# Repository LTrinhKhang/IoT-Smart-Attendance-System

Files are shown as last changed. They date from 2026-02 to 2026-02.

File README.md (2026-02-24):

# IoT Biometric Attendance System

Full-stack IoT biometric attendance system integrating custom PCB hardware, ESP32-S3 firmware, and a centralized Node.js backend.

This project demonstrates system-level engineering across hardware design, embedded development, and backend architecture.

---

## System Overview

The system consists of three major components:

1. **Hardware – ESP32-S3-Biometric-PCB**
   - Custom 2-layer PCB
   - TPS62130 synchronous buck regulator
   - ESP32-S3-WROOM module
   - TFT SPI display
   - Optical fingerprint sensor
   - Li-ion powered architecture

2. **Firmware – ESP32-S3-Firmware-Biometric**
   - Written in C++ (Arduino framework)
   - LVGL-based touchscreen UI
   - Fingerprint template handling (Base64 encoding/decoding)
   - Camera streaming support
   - HTTP client + WebSocket communication
   - NTP time synchronization

3. **Backend – Biometric-Attendance-Server**
   - Node.js + Express REST API
   - MySQL database
   - Real-time attendance logging
   - Face recognition (128D embedding)
   - Web dashboard for management and reporting

---

## High-Level Architecture

Edge Device (ESP32-S3)
→ HTTP REST / WebSocket
→ Node.js Server
→ MySQL Database

Biometric workflow:
- Face recognition using vector comparison
- Fingerprint verification via template matching
- Attendance event logging with timestamp

---

## Engineering Scope

This project covers:

- Custom PCB design with power integrity considerations
- High-frequency buck layout optimization (2.4 MHz switching)
- EMI mitigation strategies
- Embedded firmware architecture and state machine control
- Biometric data processing and encoding
- Backend API and database schema design
- Distributed IoT communication model

---

## Project Structure
- ESP32-S3-Biometric-PCB/ # Hardware design (KiCad + Gerber)
- ESP32-S3-Firmware-Biometric/ # ESP32 firmware
- Biometric-Attendance-Server/ # Node.js backend
- images/ # PCB renders and system illustrations

---

## Key Technical Highlights

- 3.3V rail designed for 1.5A peak load
- Oversized power trace for reduced IR drop
- Minimized buck hot-loop area
- Thermal vias under regulator
- Antenna keepout respected
- DRC-clean and fabrication-ready Gerber

---

## Setup Overview

### Hardware
Refer to:
`ESP32-S3-Biometric-PCB/README.md`

### Firmware
- Configure WiFi credentials
- Set server IP and port
- Flash using Arduino IDE or PlatformIO

### Server
- Install Node.js (v16+)
- Configure `.env`
- Run:  npm install
        node server/index.js

---

## Future Improvements

- Migration to 4-layer PCB for improved EMI control
- Enhanced transient response validation
- TLS-secured communication
- OTA firmware updates

---

## License

MIT (or specify applicable license)

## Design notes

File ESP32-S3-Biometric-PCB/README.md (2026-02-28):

# ESP32-S3 Biometric Attendance – Custom PCB Design

## Project Overview

This project presents a custom 2-layer PCB designed for a biometric attendance device based on ESP32-S3.  
The design integrates power management, high-speed SPI routing, and mixed-signal layout considerations in a compact form factor.

---
# Schematic Overview

<p align="center">
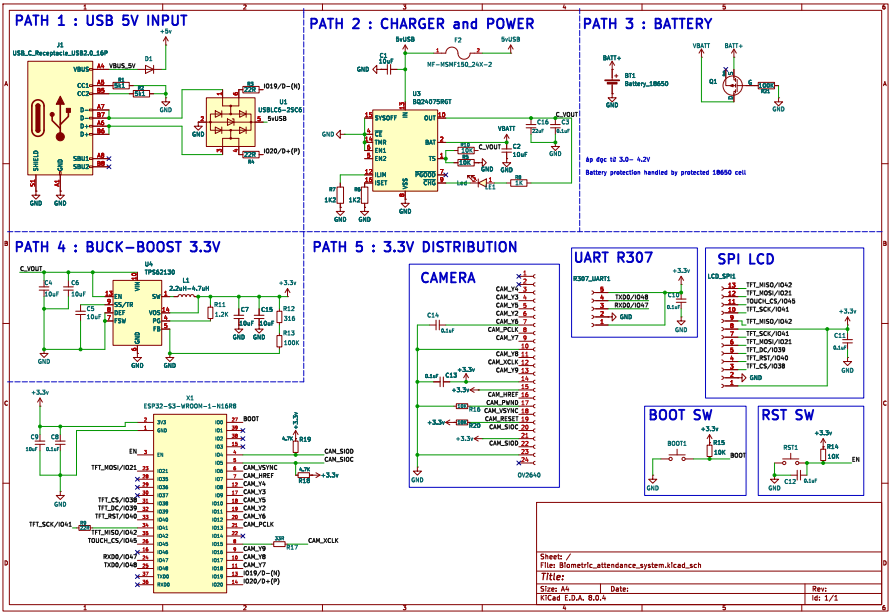
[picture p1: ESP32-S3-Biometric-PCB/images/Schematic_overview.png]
  
</p>

---

## PCB Layout Overview

### Top Copper Layer
<p align="center">
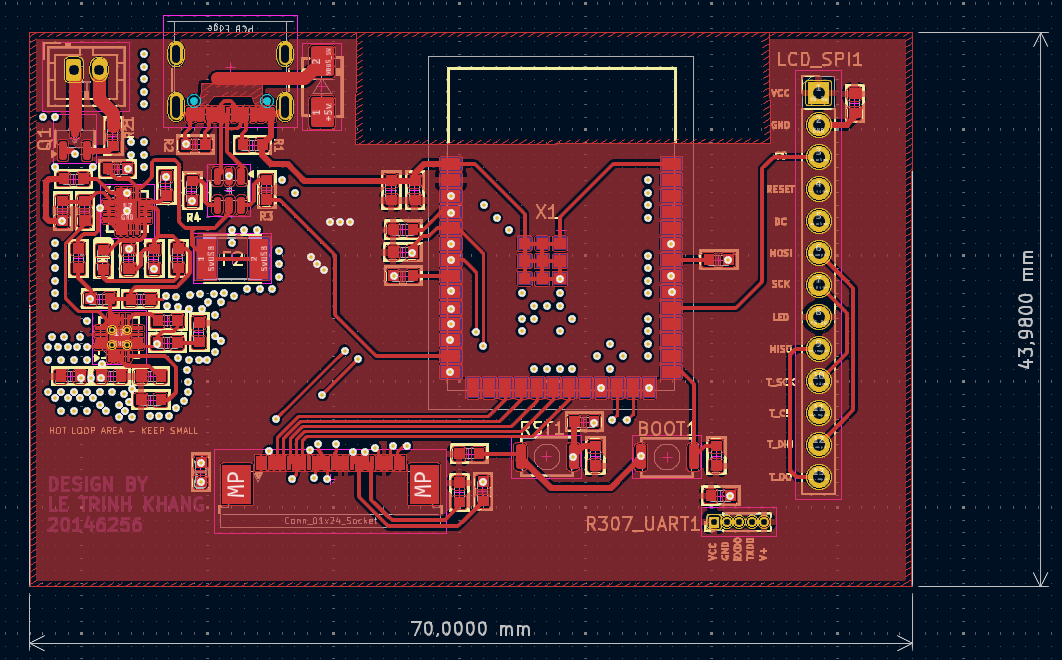
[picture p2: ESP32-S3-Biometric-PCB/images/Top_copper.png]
  
</p>

### Bottom Copper Layer
<p align="center">
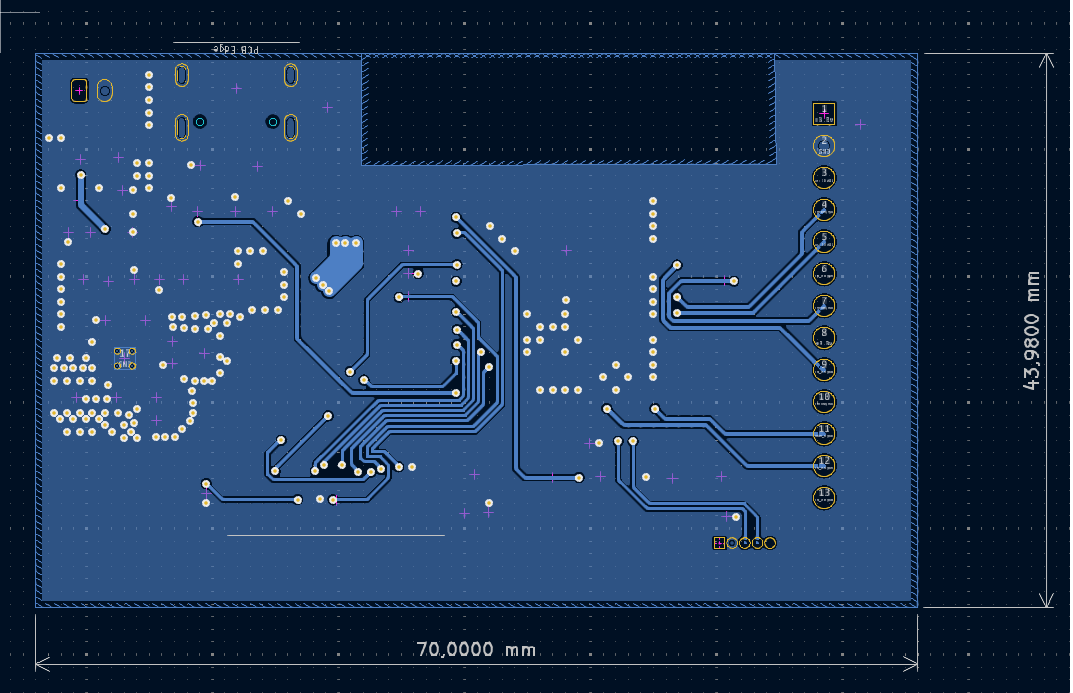
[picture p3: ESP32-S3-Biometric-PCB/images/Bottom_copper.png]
  
</p>

---

## Power Stage Layout (Buck Converter Optimization)

### Buck Layout – Hot Loop Minimization
<p align="center">
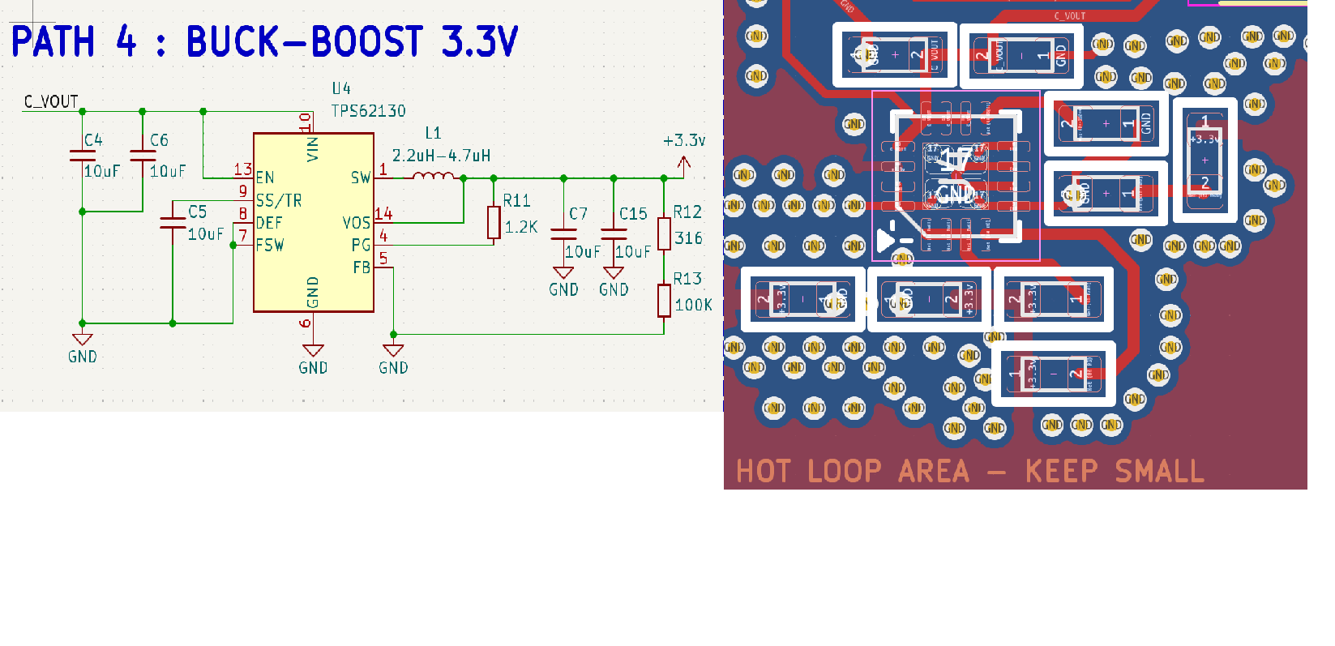
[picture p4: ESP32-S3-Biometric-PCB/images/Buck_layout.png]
  
</p>

The TPS62130 switching regulator layout prioritizes:

- Minimal VIN → SW → Inductor → CIN return loop area  
- Short SW node (~3 mm) to reduce radiated EMI  
- Tight PGND current return  
- Input capacitor placed within millimeters of VIN and PGND pins  

---

## 3D Board Rendering

### 3D Top View
<p align="center">
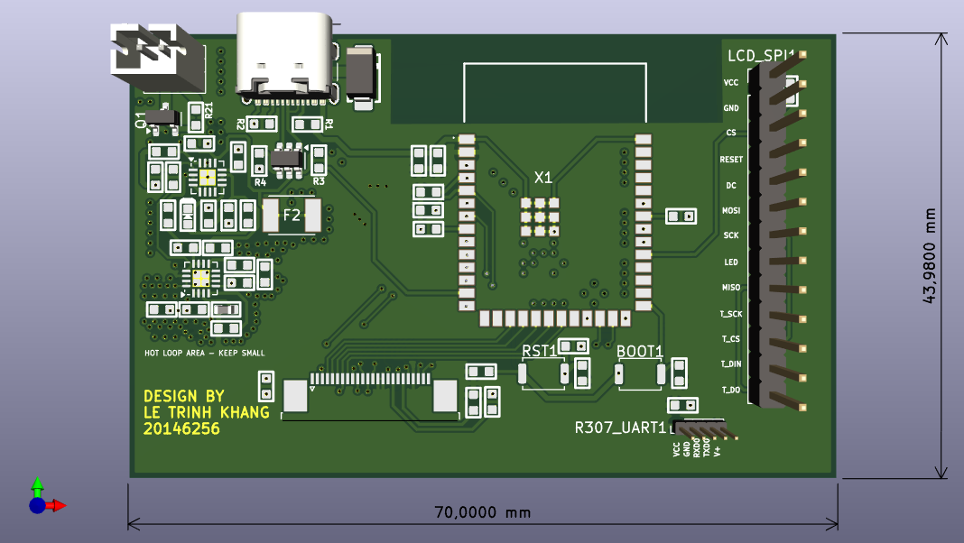
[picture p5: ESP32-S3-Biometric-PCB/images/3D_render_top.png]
  
</p>

### 3D Bottom View
<p align="center">
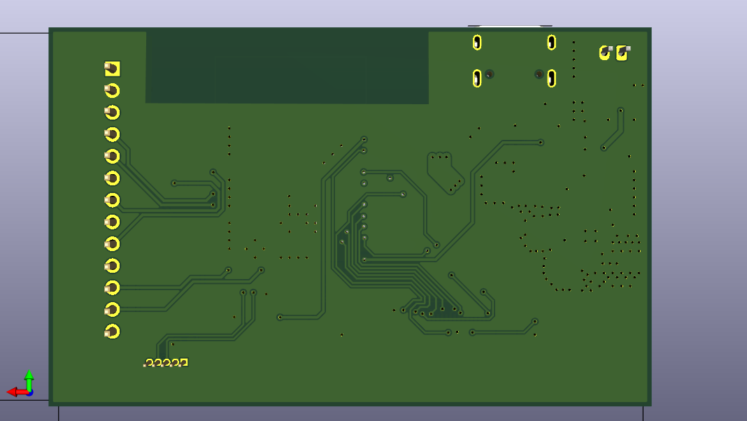
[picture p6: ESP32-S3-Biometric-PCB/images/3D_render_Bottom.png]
  
</p>

---

## Hardware Specifications

- **Layer Count**: 2-layer FR4  
- **Copper Weight**: 1 oz  
- **Board Size**: 70 × 44 mm  
- **Min Trace/Space**: 0.15 mm  
- **Min Drill**: 0.30 mm  
- **Ground Strategy**: Continuous bottom ground plane  

---

## Power Design

- **Regulator**: Step-down buck converter (3.0–4.2V → 3.3V)  
- **Controller**: TPS62130 (~2.4 MHz switching frequency)  
- **Optimization**:
  - Minimized hot loop area  
  - Proper CIN placement  
  - Thermal vias under IC  
  - Wide 3.3V power rail  

---

## Current & Trace Width Justification

The 3.3V rail supports up to **1.5A load current**, including:

- ESP32-S3 WiFi burst current  
- TFT backlight  
- Fingerprint sensor  
- Safety design margin  

Based on IPC-2221 (1 oz copper, 10°C rise):

- Required trace width ≈ 0.8 mm  
- Implemented trace width = 1.5 mm  

This reduces voltage drop and improves transient stability during high current spikes.

---

## EMI Consideration

Due to high dv/dt and di/dt at the switching node:

- SW trace length minimized (~3 mm)  
- Loop inductance reduced to limit ringing  
- Ground return path kept compact  
- No signal routing under SW node  
- ESP32 antenna keepout strictly respected  

Increasing SW trace length (e.g., 15 mm) would increase loop inductance and radiated EMI.

---

## RF Considerations

- Antenna keepout region respected  
- No copper or ground plane under antenna  
- Controlled ground reference near RF section  

These measures preserve WiFi/BT performance.

---

## Manufacturing

**During DRC validation, the following were corrected:**

- Hole clearance violations resolved  
- Drill size adjusted from 0.2 mm → 0.3 mm  
- Thermal relief optimized  
- Via stitching added for current spreading  
- Final DRC: clean before Gerber generation  

Fully compatible with standard fabrication services (JLCPCB, PCBWay).

---

## Future Improvements

- 4-layer stackup for improved EMI control and return path integrity  
- Further decoupling network optimization  
- Dedicated RF ground stitching zone

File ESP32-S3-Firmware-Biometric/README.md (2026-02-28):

# Biometric Attendance Firmware

This directory contains the ESP32-S3 firmware for the biometric attendance device. It handles user interaction via a touchscreen, biometric data processing, and communication with the central server.

## Features

- **Touchscreen UI**: Built with LVGL for a smooth and intuitive user experience.
- **Biometric Enrollment**: Supports fingerprint scanning and registration.
- **Camera Streaming**: Real-time camera feed for face recognition.
- **NTP Sync**: Automatic time synchronization via WiFi.
- **HTTP Client**: Seamless communication with the Node.js backend.

## Hardware Requirements

- **Microcontroller**: ESP32-S3 (with PSRAM enabled).
- **Display**: 3.5" or 4.3" TFT with capacitive touch.
- **Fingerprint Sensor**: R503 or compatible UART sensor.
- **Camera**: OV2640 or compatible module.

## Configuration

Before flashing, you must configure the following:

1.  **WiFi Credentials**: Usually configured through the UI on first boot or hardcoded in `wifi_ntp.cpp`.
2.  **Server IP**: Open `http_client.cpp` and update the `serverIP` and `serverPort` variables:
    ```cpp
    String serverIP = "YOUR_SERVER_IP"; 
    int serverPort = 5500;
    ```

## Installation

1.  Open the project in **Arduino IDE** or **VS Code with PlatformIO**.
2.  Install the required libraries:
    - `lvgl`
    - `ArduinoJson`
    - `TJpg_Decoder`
    - `ESP32 Camera`
3.  Select your board: **ESP32-S3 Dev Module**.
4.  Enable **PSRAM** in the Arduino IDE settings (OPI or QSPI depending on your module).
5.  Click **Upload**.

## File Structure

- `LVGL_PSRAM_1.ino`: Main entry point.
- `lvgl_ui.cpp/h`: UI screens and logic.
- `Finger.cpp/h`: Fingerprint sensor driver and logic.
- `http_client.cpp/h`: Backend communication.
- `camera_stream.cpp/h`: Camera initialization and frame handling.

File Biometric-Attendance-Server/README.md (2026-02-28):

# Attendance System Server

This is the backend server for the IoT Smart Attendance System. It provides a REST API for the ESP32-S3 device and a web dashboard for management.

## Features

- **Employee/Student Management**: CRUD operations for attendance participants.
- **Attendance Logging**: Real-time logging from both fingerprint and face recognition.
- **Face Recognition**: Integrated face recognition using `face-api.js` (client-side) and server-side storage.
- **Real-time Dashboard**: Monitor attendance as it happens.
- **Data Export**: Export attendance records (e.g., to Excel/XLSX).

## Tech Stack

- **Backend**: Node.js, Express.
- **Database**: MySQL.
- **Frontend**: HTML, CSS, JavaScript (Vanilla), FullCalendar.

## Setup Instructions

### 1. Prerequisites
- Node.js installed.
- MySQL Server running.

### 2. Database Configuration
Create a `.env` file in the `server/` root with the following variables:
```env
DB_HOST=localhost
DB_USER=root
DB_PASSWORD=your_password
DB_NAME=attendance_db
PORT=5500
```

*Note: Ensure you have a `config/db.js` that connects to MySQL using these credentials.*

### 3. Installation
1.  Navigate to the server directory:
    ```bash
    cd server
    ```
2.  Install dependencies:
    ```bash
    npm install
    ```

### 4. Running the Server
```bash
node server/index.js
```
The server will start on `http://localhost:5500`.

## File Structure

- `server/index.js`: Main entry point.
- `server/controllers/`: Business logic for each route.
- `server/models/`: Database schemas and queries.
- `server/routes/`: API endpoint definitions.
- `public/`: Frontend assets (HTML, CSS, JS).
- `public/faces/`: Stored face images for recognition.

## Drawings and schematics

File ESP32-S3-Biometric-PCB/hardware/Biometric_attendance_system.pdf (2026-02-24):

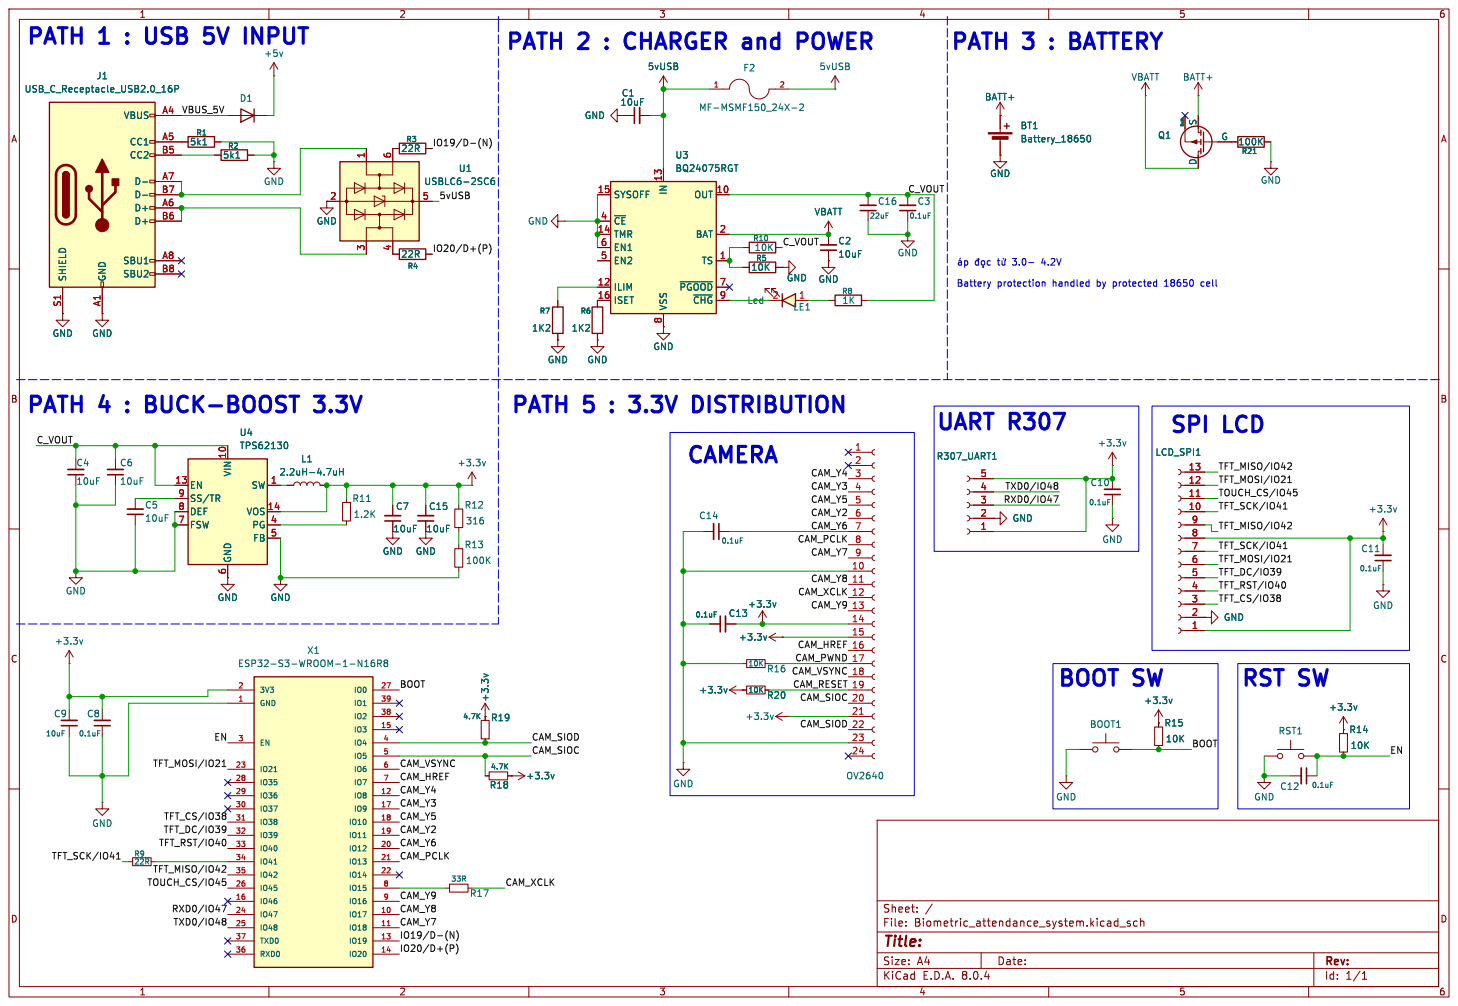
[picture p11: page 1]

6 FSW 7 DEF 8 SS/TR 9 U4 TPS62130 C11

6 FSW 7 DEF 8 SS/TR 9 GND GND

Id: 1/1 Title: File: Biometric_attendance_system.kicad_sch Sheet: /

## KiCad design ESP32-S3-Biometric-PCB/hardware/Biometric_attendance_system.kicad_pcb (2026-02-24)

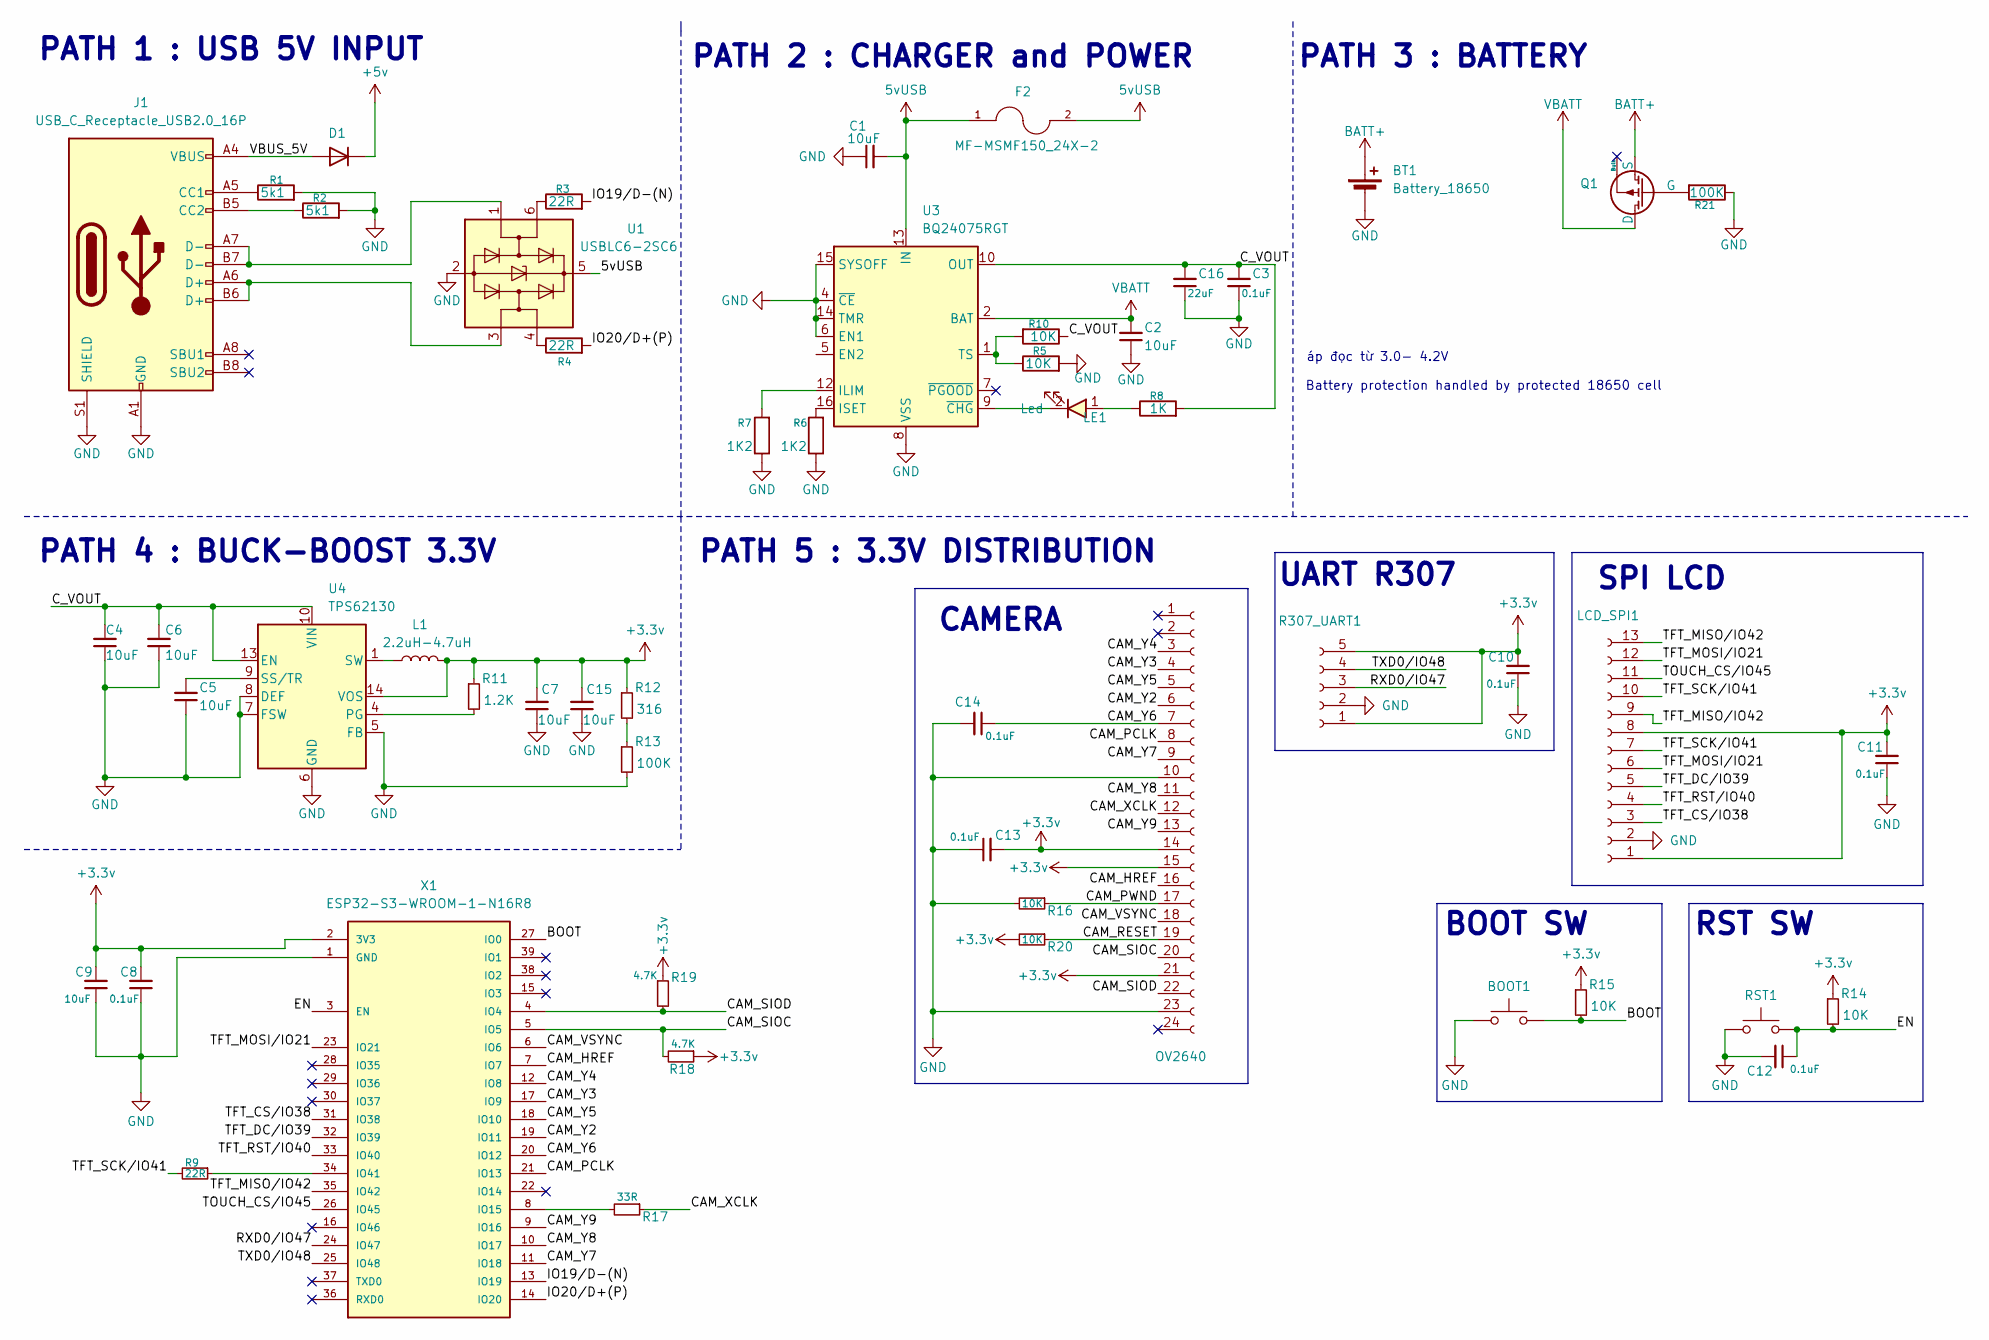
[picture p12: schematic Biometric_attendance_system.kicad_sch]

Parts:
BOOT1: SW_Push; SW_Push_SPST_NO_Alps_SKRK
BT1: Battery_18650; JST_PH_B2B-PH-K_1x02_P2.00mm_Vertical
C1, C2, C4, C5, C6, C7, C9, C15: 10uF; C_0603
C3, C8, C10, C11, C12, C13, C14: 0.1uF; C_0603
C16: 22uF; C_0603
D1: D; Package-Diode-D_SMA
F2: MF-MSMF150_24X-2; FUSER_MF-MSMF150_24X-2
J1: USB_C_Receptacle_USB2.0_16P; USB_C_Receptacle_GCT_USB4105-xx-A_16P_TopMnt_Horizontal
L1: 2.2uH-4.7uH; L_0603
LCD_SPI1: Conn_01x13_Socket; PinHeader_1x13_P2.54mm_Vertical
LE1: Led; LED_0603
OV2640: Conn_01x24_Socket; TE_2-1734839-4_1x24-1MP_P0.5mm_Horizontal
Q1: PMOS_Substrate; SOT-23
R1, R2: 5k1; R_0603
R3, R4, R9: 22R; R_0603
R5, R10, R14, R15, R16, R20: 10K; R_0603
R6, R7: 1K2; R_0603
R8: 1K; R_0603
R11: 1.2K; R_0603
R12: 316; R_0603
R13, R21: 100K; R_0603
R17: 33R; R_0603
R18, R19: 4.7K; R_0603
R307_UART1: Conn_01x05_Socket; PinHeader_1x05_P1.00mm_Vertical
RST1: SW_Push; SW_Push_SPST_NO_Alps_SKRK
U1: USBLC6-2SC6; SOT-23-6
U3: BQ24075RGT; VQFN-16-1EP_3x3mm_P0.5mm_EP1.6x1.6mm
U4: TPS62130; VQFN-16-1EP_3x3mm_P0.5mm_EP1.68x1.68mm_ThermalVias
X1: ESP32-S3-WROOM-1-N16R8; ESP32S3WROOM1N8R2; MANUFACTURER_PART_NUMBER ESP32-S3-WROOM-1-N16R8

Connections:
5vUSB: C1.2, F2.1, F2.2, U1.5 (VBUS), U3.13 (IN)
+3.3v: C7.2, C8.2, C9.2, C10.2, C11.2, C13.2, C15.2, L1.2, LCD_SPI1.1, LCD_SPI1.8, OV2640.14, OV2640.15, OV2640.21, R11.1, R12.1, R14.1, R15.1, R18.1, R19.1, R20.2, R307_UART1.1, R307_UART1.5, U4.14 (VOS), X1.2 (3V3)
+5v: D1.1 (K)
/BOOT: BOOT1.2, R15.2, X1.27 (IO0)
/CAM_HREF: OV2640.16, X1.7 (IO7)
/CAM_PCLK: OV2640.8, X1.21 (IO13)
/CAM_PWND: OV2640.17, R16.1
/CAM_RESET: OV2640.19, R20.1
/CAM_SIOC: OV2640.20, R18.2, X1.5 (IO5)
/CAM_SIOD: OV2640.22, R19.2, X1.4 (IO4)
/CAM_VSYNC: OV2640.18, X1.6 (IO6)
/CAM_XCLK: OV2640.12, R17.1
/CAM_Y2: OV2640.6, X1.19 (IO11)
/CAM_Y3: OV2640.4, X1.17 (IO9)
/CAM_Y4: OV2640.3, X1.12 (IO8)
/CAM_Y5: OV2640.5, X1.18 (IO10)
/CAM_Y6: C14.1, OV2640.7, X1.20 (IO12)
/CAM_Y7: OV2640.9, X1.11 (IO18)
/CAM_Y8: OV2640.11, X1.10 (IO17)
/CAM_Y9: OV2640.13, X1.9 (IO16)
/C_VOUT: C3.2, C4.2, C6.2, C16.2, R8.2, R10.1, U3.10 (OUT), U3.11 (OUT), U4.10 (VIN), U4.11 (VIN), U4.12 (VIN), U4.13 (EN)
/EN: C12.1, R14.2, RST1.2, X1.3 (EN)
/IO19/D-(N): R3.2, X1.13 (IO19)
/IO20/D+(P): R4.2, X1.14 (IO20)
/RXD0/IO47: R307_UART1.3, X1.24 (IO47)
/TFT_CS/IO38: LCD_SPI1.3, X1.31 (IO38)
/TFT_DC/IO39: LCD_SPI1.5, X1.32 (IO39)
/TFT_MISO/IO42: LCD_SPI1.9, LCD_SPI1.13, X1.35 (IO42)
/TFT_MOSI/IO21: LCD_SPI1.6, LCD_SPI1.12, X1.23 (IO21)
/TFT_RST/IO40: LCD_SPI1.4, X1.33 (IO40)
/TFT_SCK/IO41: LCD_SPI1.7, LCD_SPI1.10, R9.2
/TOUCH_CS/IO45: LCD_SPI1.11, X1.26 (IO45)
/TXD0/IO48: R307_UART1.4, X1.25 (IO48)
/VBUS_5V: D1.2 (A), J1.A4 (VBUS), J1.A9 (VBUS), J1.B4 (VBUS), J1.B9 (VBUS)
BATT+: BT1.1 (+), Q1.3 (S)
GND: BOOT1.1, BT1.2 (-), C1.1, C2.1, C3.1, C4.1, C5.1, C6.1, C7.1, C8.1, C9.1, C10.1, C11.1, C12.2, C13.1, C14.2, C15.1, C16.1, J1.A1 (GND), J1.A12 (GND), J1.B1 (GND), J1.B12 (GND), J1.S1 (SHIELD), LCD_SPI1.2, OV2640.10, OV2640.23, R1.2, R2.2, R5.2, R6.1, R7.1, R13.2, R16.2, R21.1, R307_UART1.2, RST1.1, U1.2 (GND), U3.4 (~CE), U3.5 (EN2), U3.6 (EN1), U3.8 (VSS), U3.14 (TMR), U3.15 (SYSOFF), U3.17 (VSS), U4.5 (FB), U4.6 (GND), U4.7 (FSW), U4.8 (DEF), U4.15 (GND), U4.16 (GND), U4.17 (GND), X1.1 (GND), X1.40 (GND), X1.41 (GND), X1.42 (GND), X1.43 (GND), X1.44 (GND), X1.45 (GND), X1.46 (GND), X1.47 (GND), X1.48 (GND), X1.49 (GND)
unnamed: J1.A5 (CC1), R1.1
unnamed: J1.B5 (CC2), R2.1
unnamed: J1.A6 (D+), J1.B6 (D+), U1.3 (I/O2)
unnamed: J1.A7 (D-), J1.B7 (D-), U1.1 (I/O1)
unnamed: L1.1, U4.1 (SW), U4.2 (SW), U4.3 (SW)
unnamed: LE1.1, R8.1
unnamed: Q1.2 (G), R21.2
unnamed: R3.1, U1.6 (I/O1)
unnamed: R4.1, U1.4 (I/O2)
unnamed: R12.2, R13.1
unnamed: R7.2, U3.12 (ILIM)
unnamed: R6.2, U3.16 (ISET)
unnamed: R5.1, R10.2, U3.1 (TS)
unnamed: LE1.2, U3.9 (~CHG)
unnamed: R11.2, U4.4 (PG)
unnamed: C5.2, U4.9 (SS/TR)
unnamed: R17.2, X1.8 (IO15)
unnamed: R9.1, X1.34 (IO41)
VBATT: C2.2, Q1.1 (D), U3.2 (BAT), U3.3 (BAT)

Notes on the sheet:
UART R307
SPI LCD
PATH 5 : 3.3V DISTRIBUTION
PATH 4 : BUCK-BOOST 3.3V
PATH 2 : CHARGER and POWER
CAMERA
áp đọc từ 3.0- 4.2V
PATH 3 : BATTERY
BOOT SW
Battery protection handled by protected 18650 cell
PATH 1 : USB 5V INPUT
RST SW

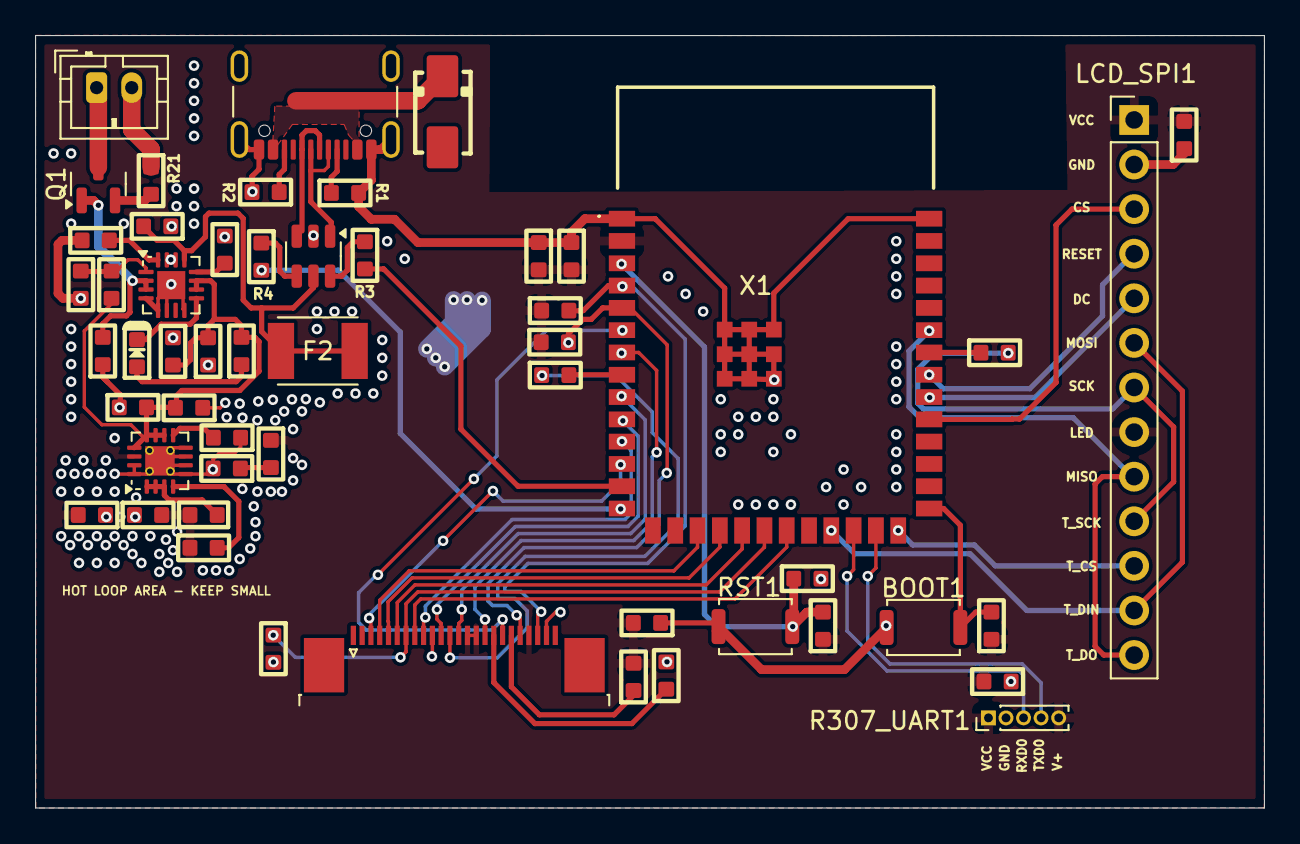
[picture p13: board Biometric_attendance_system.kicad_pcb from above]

Board: 2 copper layers, 70.0 x 44.0 mm, 53 parts (0 on the bottom side), 54 nets.

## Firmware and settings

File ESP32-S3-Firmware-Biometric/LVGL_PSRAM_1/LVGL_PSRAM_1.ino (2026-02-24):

#include "lvgl_ui.h"
#include "wifi_ntp.h"
#include "display_touch.h"
#include "lvgl_setup.h"
#include "camera_stream.h"
#include "Finger.h"
#include "fingerprint_storage.h"
#include "wifiScreen.h"
#include <TJpg_Decoder.h>  // Đảm bảo đã include thư viện TJpg_Decoder
#include "http_client.h"
#include "fingerprint_ui.h"

// Biến toàn cục để theo dõi timer
lv_timer_t *camera_update_timer = NULL;

// Hàm timer cập nhật camera stream
void camera_timer_cb(lv_timer_t * timer) {
    if (camera_streaming && camera_img) {
        update_camera_widget(camera_img);
    } else if (!camera_streaming && timer) {
        // Nếu không còn streaming nhưng timer vẫn hoạt động, tạm dừng nó
        lv_timer_pause(timer);
    }
}

void setup() {
    Serial.begin(115200);
    Serial.println("Khởi động ESP32-S3...");

    Serial.printf("Total PSRAM: %d bytes\n", ESP.getPsramSize());
    Serial.printf("Free PSRAM (Before Allocation): %d bytes\n", ESP.getFreePsram());
    
    // Khởi tạo module vân tay
    if (fingerprint.begin()) {
        Serial.println("Cảm biến vân tay đã sẵn sàng!");
    } else {
        Serial.println("Không thể kết nối với cảm biến vân tay!");
    }

    init_lvgl_buffers();
    
    // Khởi tạo WiFi
    Serial.println("Khởi tạo WiFi...");
    WiFi.mode(WIFI_STA);
    WiFi.disconnect(true);  // Xóa cấu hình cũ
    delay(500);  // Tăng delay để đảm bảo WiFi reset hoàn toàn

    init_display();
    init_touch();
    TJpgDec.setCallback(tft_output);
    init_camera();
    init_lvgl();
    create_wifi_screen();          // Tạo màn hình WiFi
    lv_scr_load(wifiScreen);


    // Tạo task stream riêng biệt ở core 1
    xTaskCreatePinnedToCore(
      stream_task,        // Hàm task chạy nền
      "Camera Stream",    // Tên
      10000,               // Stack size
      NULL,               // Tham số
      1,                  // Ưu tiên
      NULL,               // Handle
      0                   // Core 1
    );

    // Tạo timer LVGL để cập nhật stream từ camera mỗi 100ms
    camera_update_timer = lv_timer_create(camera_timer_cb, 100, NULL);
    // Tạm dừng timer ban đầu vì chưa cần streaming
    lv_timer_pause(camera_update_timer);
    
    // Hiển thị số lượng mẫu vân tay đã lưu
    uint16_t templateCount = fingerprint.getTemplateCount();
    Serial.printf("Số lượng mẫu vân tay đã lưu: %d\n", templateCount);

    Serial.printf("Free heap: %d bytes\n", esp_get_free_heap_size());
}

// Biến để theo dõi bộ nhớ
static unsigned long lastMemCheck = 0;
static uint32_t lastFreeHeap = 0;
static uint32_t lastFreePsram = 0;

void loop() {
    
    lv_task_handler();

    if (isStreamActive && camera_streaming) {
        camera_stream_server_handle();
    }
    if (shouldDeleteFpTimer && fpTimer) {
      lv_timer_del(fpTimer);
      fpTimer = NULL;
      shouldDeleteFpTimer = false;
      Serial.println("fpTimer deleted safely in loop");
    }
    // Kiểm tra bộ nhớ mỗi 10 giây
    unsigned long currentMillis = millis();
    if (currentMillis - lastMemCheck > 10000) {
        uint32_t freeHeap = esp_get_free_heap_size();
        uint32_t freePsram = ESP.getFreePsram();
        
        // Kiểm tra stack usage
        UBaseType_t stackHighWaterMark = uxTaskGetStackHighWaterMark(NULL);
        
        // Chỉ in ra nếu có thay đổi đáng kể (>5KB) hoặc stack thấp
        if (abs((int32_t)freeHeap - (int32_t)lastFreeHeap) > 5000 || 
            abs((int32_t)freePsram - (int32_t)lastFreePsram) > 5000 ||
            stackHighWaterMark < 1000) {  // Cảnh báo nếu stack còn < 1KB
            Serial.printf("Free heap: %d bytes, Free PSRAM: %d bytes, Stack free: %d bytes\n", 
                         freeHeap, freePsram, stackHighWaterMark * sizeof(StackType_t));
            
            if (stackHighWaterMark < 1000) {
                Serial.println("CẢNH BÁO: Stack sắp hết!");
            }
            
            // Nếu heap quá thấp, thực hiện các biện pháp khẩn cấp
            if (freeHeap < 20000) {
                Serial.println("⚠️ HEAP THẤP - Thực hiện dọn dẹp khẩn cấp");
                
                // Dừng camera stream nếu đang chạy
                if (camera_streaming) {
                    camera_streaming = false;
                    stop_camera_stream_server();
                    Serial.println("🛑 Đã dừng camera stream để tiết kiệm bộ nhớ");
                }
                
                // Force garbage collection
                esp_restart();  // Restart nếu heap quá thấp
            }
            
            lastFreeHeap = freeHeap;
            lastFreePsram = freePsram;
        }
        
        lastMemCheck = currentMillis;
    }
    
    delay(5);
}

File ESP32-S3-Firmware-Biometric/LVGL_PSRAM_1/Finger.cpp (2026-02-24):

#include "Finger.h"
#include <base64.h>
#include "http_client.h"
#include "mbedtls/base64.h"
#include "globals.h"
#include "fingerprint_storage.h"


// Initialize the global instances
HardwareSerial FPSerial(2);
FingerprintModule fingerprint(&FPSerial, FP_RX_PIN, FP_TX_PIN);

#define FINGERPRINT_DATA    0x02
#define FINGERPRINT_ENDDATA 0x08
// #define FINGERPRINT_COMMANDPACKET 0x01
#define FINGERPRINT_STARTCODE 0xEF01


FingerprintModule::FingerprintModule(HardwareSerial* serial, uint8_t rxPin, uint8_t txPin, uint32_t baud)
  : finger(serial), hwSerial(serial), rx(rxPin), tx(txPin), baudrate(baud), lastConfidence(0) {}

bool FingerprintModule::begin() {
  // Initialize serial communication with the fingerprint sensor
  hwSerial->begin(baudrate, SERIAL_8N1, rx, tx);
  finger.begin(baudrate);
  
  // Initialize fingerprint storage
  if (!fpStorage.begin()) {
    Serial.println("⚠️ Không thể khởi tạo storage cho mapping vân tay");
  } else {
    Serial.println("✅ Storage mapping vân tay đã sẵn sàng");
    Serial.printf("📊 Số vân tay đã đăng ký: %d/127\n", fpStorage.getRegisteredCount());
  }
  
  // Verify the sensor is responding with correct password
  bool success = finger.verifyPassword();
  if (!success) {
    Serial.println("Không thể kết nối với cảm biến vân tay!");
    Serial.println("Kiểm tra lại kết nối và nguồn điện.");
  } else {
    Serial.println("Cảm biến vân tay đã sẵn sàng!");
  }
  return success;
}

int8_t FingerprintModule::startEnrollment(FingerprintCallback statusCallback) {
  if (statusCallback) {
    statusCallback(0, "Bắt đầu quá trình đăng ký vân tay mới");
    statusCallback(0, "Nhập ID từ 1 đến 127:");
  } else {
    Serial.println("=== ĐĂNG KÝ VÂN TAY MỚI ===");
    Serial.println("Nhập ID từ 1 đến 127:");
  }
  
  uint8_t id = readNumber();
  if (id == 0 || id > 127) {
    const char* msg = "ID không hợp lệ. Phải từ 1-127.";
    if (statusCallback) statusCallback(-1, msg);
    else Serial.println(msg);
    return -1;
  }
  
  return enrollFingerprint(id, statusCallback);
}

int8_t FingerprintModule::enrollFingerprint(uint32_t mssv, FingerprintCallback statusCallback) {
    uint8_t sensor_id;

    if (fpStorage.isMSSVRegistered(mssv)) {
        // Đã đăng ký → lấy lại ID cảm biến cũ
        sensor_id = fpStorage.getSensorIDFromMSSV(mssv);
        Serial.printf("♻️ MSSV %d đã tồn tại → ghi đè tại ID %d\n", mssv, sensor_id);

        // Xóa mẫu cũ trên cảm biến
        finger.deleteModel(sensor_id);

        // Xóa mapping cũ để ghi lại
        fpStorage.deleteMSSVMapping(mssv);
    } else {
        // MSSV chưa đăng ký → cấp ID mới theo thứ tự
        sensor_id = fpStorage.getNextAvailableID();
        if (sensor_id == 0) {
            if (statusCallback) statusCallback(-1, "Cảm biến đã đầy (127 vân tay)");
            Serial.println("❌ Cảm biến đã đầy");
            return -2;
        }
        Serial.printf("🆕 Tạo ID mới: %d cho MSSV: %d\n", sensor_id, mssv);
    }

    // Hiển thị thông báo
    if (statusCallback) {
        char msg[128];  // Tăng kích thước buffer
        snprintf(msg, sizeof(msg), "Dang ky MSSV %lu vao ID %d", (unsigned long)mssv, sensor_id);
        statusCallback(0, msg);
    }

    if (statusCallback) statusCallback(0, "🟡 Bắt đầu đăng ký vân tay...");

    Serial.println("📸 Chụp lần 1...");
    while (finger.getImage() != FINGERPRINT_OK);
    if (finger.image2Tz(1) != FINGERPRINT_OK) {
        if (statusCallback) statusCallback(-1, "Lỗi chuyển ảnh lần 1");
        return -3;
    }

    delay(500);
    Serial.println("📸 Chụp lần 2...");
    while (finger.getImage() != FINGERPRINT_OK);
    if (finger.image2Tz(2) != FINGERPRINT_OK) {
        if (statusCallback) statusCallback(-1, "Lỗi chuyển ảnh lần 2");
        return -4;
    }

    Serial.println("🔄 Tạo model...");
    if (finger.createModel() != FINGERPRINT_OK) {
        if (statusCallback) statusCallback(-1, "Tạo model thất bại");
        return -5;
    }

    Serial.printf("💾 Ghi model vào flash tại ID %d...\n", sensor_id);
    if (finger.storeModel(sensor_id) != FINGERPRINT_OK) {
        if (statusCallback) statusCallback(-1, "Không lưu được mẫu");
        return -6;
    }

    // Ghi lại mapping
    if (!fpStorage.saveMSSVMapping(mssv, sensor_id)) {
        finger.deleteModel(sensor_id);
        if (statusCallback) statusCallback(-1, "Lỗi lưu mapping");
        return -7;
    }

    if (statusCallback) {
        char msg[128];  // Tăng kích thước buffer
        snprintf(msg, sizeof(msg), "Dang ky thanh cong! MSSV %lu -> ID %d", (unsigned long)mssv, sensor_id);
        statusCallback(sensor_id, msg);  // trả về ID cảm biến
    }

    Serial.printf("✅ Đăng ký thành công: MSSV %d -> ID cảm biến %d\n", mssv, sensor_id);
    Serial.printf("📊 Tổng số vân tay đã đăng ký: %d/127\n", fpStorage.getRegisteredCount());

    return sensor_id;
}



bool FingerprintModule::isMSSVRegistered(uint32_t mssv) {
    return fpStorage.isMSSVRegistered(mssv);  // gọi gián tiếp
}
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

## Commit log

2026-02-24 Initial commit - Full IoT Biometic Attendance System
    [Biometric_attendance_system.kicad_pcb, Biometric_attendance_system.kicad_sch]
2026-02-24 Update PCB render images - improved layout visibility
2026-02-24 Add PCB images to README with layout explanation
2026-02-24 Add schematic images with explanation
